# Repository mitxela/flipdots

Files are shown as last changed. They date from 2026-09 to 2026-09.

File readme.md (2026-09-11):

# Flipdot driver circuitry

KiCad designs and software for driving Hanover flipdot displays with a resolution of 13 by 28, as used in the [FLIP fluid on Flipdots project](https://mitxela.com/projects/flipflip)

- `drivers-full` are the main driver panels doing 13x8
- `drivers-half` are truncated to 13x4 for the end
- `decode` are boards with a ch32v003 to drive the shift registers
- `decode-sw` is firmware for the ch32, plus python scripts to show test patterns and video via a USB-RS485 adapter

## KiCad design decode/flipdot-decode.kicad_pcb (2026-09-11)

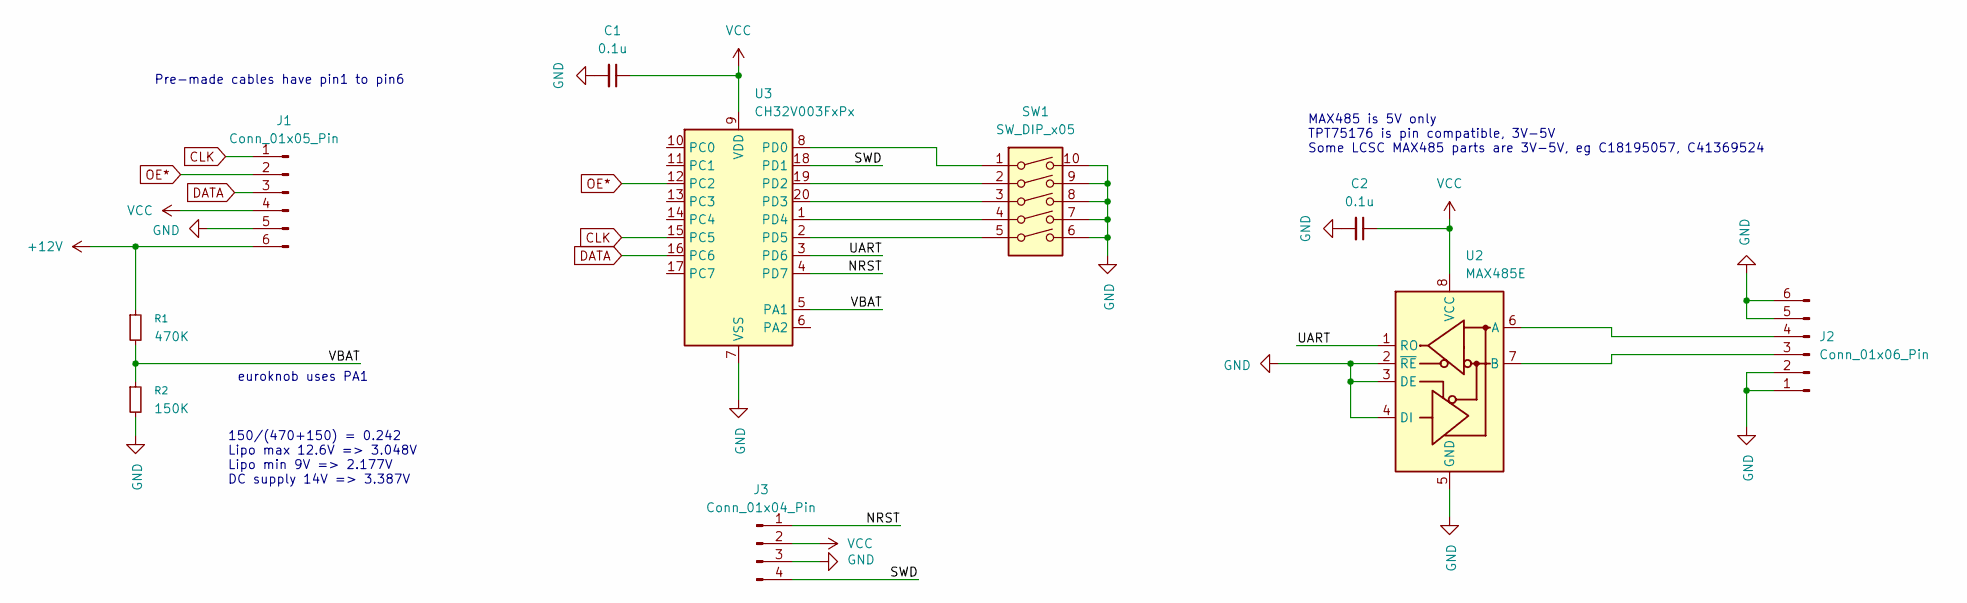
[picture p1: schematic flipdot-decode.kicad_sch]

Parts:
C1, C2: 0.1u; C_0603_1608Metric
J1: Conn_01x05_Pin; JST_ZH_B6B-ZR_1x06_P1.50mm_Vertical
J2: Conn_01x06_Pin; IDC-Header_2x03_P2.54mm_Vertical
J3: Conn_01x04_Pin; PinHeader_1x04_P2.54mm_Vertical
R1: 470K; R_0603_1608Metric
R2: 150K; R_0603_1608Metric
SW1: SW_DIP_x05; SW_DIP_SPSTx05_Slide_9.78x14.88mm_W7.62mm_P2.54mm
U2: MAX485E; SOIC-8_3.9x4.9mm_P1.27mm
U3: CH32V003FxPx; TSSOP-20_4.4x6.5mm_P0.65mm

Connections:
+12V: J1.6, R1.1
/NRST: J3.1, U3.4 (PD7)
/SWD: J3.4, U3.18 (PD1)
/UART: U2.1 (RO), U3.3 (PD6)
/VBAT: R1.2, R2.1, U3.5 (PA1)
CLK: J1.1, U3.15 (PC5)
DATA: J1.3, U3.16 (PC6)
GND: C1.2, C2.2, J1.5, J2.1, J2.2, J2.5, J2.6, J3.3, R2.2, SW1.6, SW1.7, SW1.8, SW1.9, SW1.10, U2.2 (~RE), U2.3 (DE), U2.4 (DI), U2.5 (GND), U3.7 (VSS)
unnamed: J2.3, U2.7 (B)
unnamed: J2.4, U2.6 (A)
unnamed: SW1.1, U3.8 (PD0)
unnamed: SW1.2, U3.19 (PD2)
unnamed: SW1.3, U3.20 (PD3)
unnamed: SW1.4, U3.1 (PD4)
unnamed: SW1.5, U3.2 (PD5)
OE*: J1.2, U3.12 (PC2)
VCC: C1.1, C2.1, J1.4, J3.2, U2.8 (VCC), U3.9 (VDD)

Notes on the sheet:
150/(470+150) = 0.242 Lipo max 12.6V => 3.048V Lipo min 9V => 2.177V DC supply 14V => 3.387V
euroknob uses PA1
MAX485 is 5V only TPT75176 is pin compatible, 3V-5V Some LCSC MAX485 parts are 3V-5V, eg C18195057, C41369524
Pre-made cables have pin1 to pin6

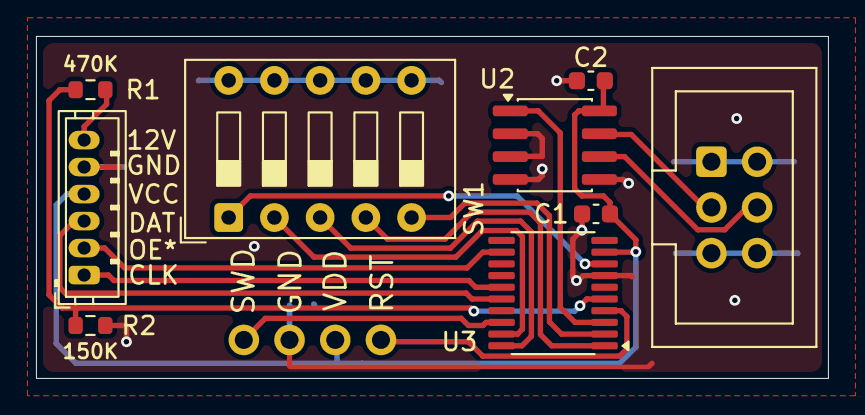
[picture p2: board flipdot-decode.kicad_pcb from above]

Board: 2 copper layers, 44.0 x 19.0 mm, 10 parts (0 on the bottom side), 17 nets.

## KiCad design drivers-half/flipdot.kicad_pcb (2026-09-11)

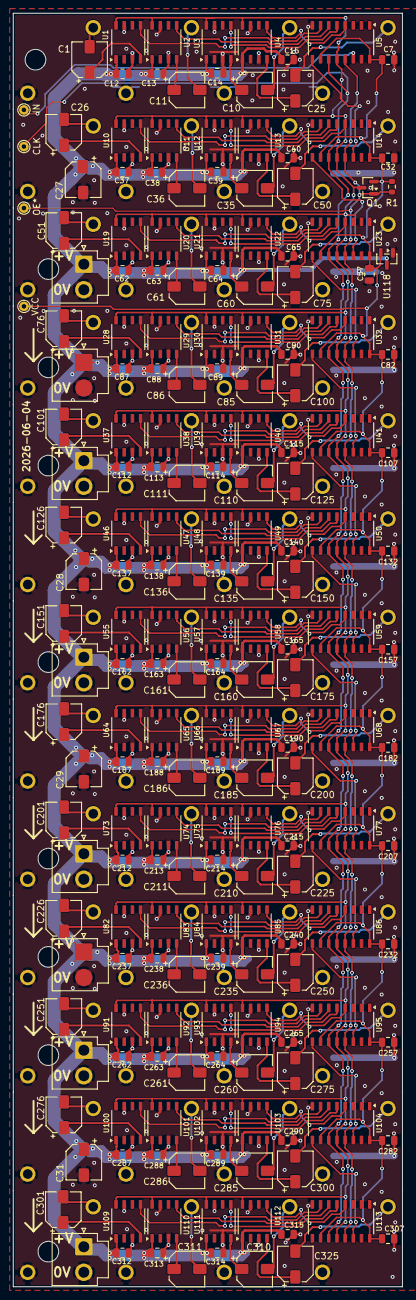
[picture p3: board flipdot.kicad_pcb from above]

Board: 2 copper layers, 60.4 x 197.5 mm, 262 parts (0 on the bottom side), 175 nets.

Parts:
C1, C10, C11, C25, C26, C27, C28, C29, C31, C35, C36, C50, C51, C60, C61, C75, C76, C85, C86, C100, C101, C110, C111, C125, C126, C135, C136, C150, C151, C160, C161, C175, C176, C185, C186, C200, C201, C210, C211, C225, C226, C235, C236, C250, C251, C260, C261, C275, C276, C285, C286, C300, C301, C310, C311, C325: 47u; CP_Elec_5x5.4_slim
C7, C12, C13, C14, C15, C32, C37, C38, C39, C40, C57, C62, C63, C64, C65, C82, C87, C88, C89, C90, C107, C112, C113, C114, C115, C132, C137, C138, C139, C140, C157, C162, C163, C164, C165, C182, C187, C188, C189, C190, C207, C212, C213, C214, C215, C232, C237, C238, C239, C240, C257, C262, C263, C264, C265, C282, C287, C288, C289, C290, C307, C312, C313, C314, C315: 10u; C_0805_2012Metric
H1, H5, H7, H9, H13, H17, H19, H21, H25: MountingHole; MountingHole_3.2mm_M3_DIN965
J10, J14, J18, J25, J34, J38, J41, J50: Conn_01x02_Pin; JST_VH_B2P-VH_1x02_P3.96mm_Vertical
L1, L2, L3, L4, L9, L10, L11, L12, L17, L18, L19, L20, L25, L26, L27, L28, L33, L34, L35, L36, L41, L42, L43, L44, L49, L50, L51, L52, L57, L58, L59, L60, L65, L66, L67, L68, L73, L74, L75, L76, L81, L82, L83, L84, L89, L90, L91, L92, L97, L98, L99, L100: Flipdot_single
Q1: FDN338P; SOT-23
R1: 100K; R_0603_1608Metric
TP1: IN; TestPoint_Pad_D1.5mm
TP4: CLK; TestPoint_Pad_D1.5mm
TP5: OE*; TestPoint_Pad_D1.5mm
TP7: VCC; TestPoint_Pad_D1.5mm
U1, U2, U3, U4, U10, U11, U12, U13, U19, U20, U21, U22, U28, U29, U30, U31, U37, U38, U39, U40, U46, U47, U48, U49, U55, U56, U57, U58, U64, U65, U66, U67, U73, U74, U75, U76, U82, U83, U84, U85, U91, U92, U93, U94, U100, U101, U102, U103, U109, U110, U111, U112: SOP-8_3.9x4.9mm_P1.27mm
U5, U14, U23, U32, U41, U50, U59, U68, U77, U86, U95, U104, U113: 74HC595; SOP-16_3.9x9.9mm_P1.27mm
U118: Megain MG6208T3-33; SOT-23

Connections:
+12V: C12.2, C13.2, C14.2, C15.2, C27.1, C28.1, C29.1, C31.1, C37.2, C38.2, C39.2, C40.2, C62.2, C63.2, C64.2, C65.2, C87.2, C88.2, C89.2, C90.2, C112.2, C113.2, C114.2, C115.2, C137.2, C138.2, C139.2, C140.2, C162.2, C163.2, C164.2, C165.2, C187.2, C188.2, C189.2, C190.2, C212.2, C213.2, C214.2, C215.2, C237.2, C238.2, C239.2, C240.2, C262.2, C263.2, C264.2, C265.2, C287.2, C288.2, C289.2, C290.2, C312.2, C313.2, C314.2, C315.2, J10.1, J14.1, J18.1, J25.1, J34.1, J38.1, J41.1, J50.1, U1.1 (VCC), U2.1 (VCC), U3.1 (VCC), U4.1 (VCC), U10.1 (VCC), U11.1 (VCC), U12.1 (VCC), U13.1 (VCC), U19.1 (VCC), U20.1 (VCC), U21.1 (VCC), U22.1 (VCC), U28.1 (VCC), U29.1 (VCC), U30.1 (VCC), U31.1 (VCC), U37.1 (VCC), U38.1 (VCC), U39.1 (VCC), U40.1 (VCC), U46.1 (VCC), U47.1 (VCC), U48.1 (VCC), U49.1 (VCC), U55.1 (VCC), U56.1 (VCC), U57.1 (VCC), U58.1 (VCC), U64.1 (VCC), U65.1 (VCC), U66.1 (VCC), U67.1 (VCC), U73.1 (VCC), U74.1 (VCC), U75.1 (VCC), U76.1 (VCC), U82.1 (VCC), U83.1 (VCC), U84.1 (VCC), U85.1 (VCC), U91.1 (VCC), U92.1 (VCC), U93.1 (VCC), U94.1 (VCC), U100.1 (VCC), U101.1 (VCC), U102.1 (VCC), U103.1 (VCC), U109.1 (VCC), U110.1 (VCC), U111.1 (VCC), U112.1 (VCC), U118.3 (VI)
/row1/DATA_IN: TP1.1 (1_1), U5.14 (SER)
/row1/DATA_OUT: U5.9 (QH'), U14.14 (SER)
/row2/DATA_OUT: U14.9 (QH'), U23.14 (SER)
/row3/DATA_OUT: U23.9 (QH'), U32.14 (SER)
/row4/DATA_OUT: U32.9 (QH'), U41.14 (SER)
/row5/DATA_OUT: U41.9 (QH'), U50.14 (SER)
/row6/DATA_OUT: U50.9 (QH'), U59.14 (SER)
/row7/DATA_OUT: U59.9 (QH'), U68.14 (SER)
/row8/DATA_OUT: U68.9 (QH'), U77.14 (SER)
/row10/DATA_IN: U77.9 (QH'), U86.14 (SER)
/row10/DATA_OUT: U86.9 (QH'), U95.14 (SER)
/row11/DATA_OUT: U95.9 (QH'), U104.14 (SER)
/row12/DATA_OUT: U104.9 (QH'), U113.14 (SER)
CLK: TP4.1 (1_1), U5.11 (SRCLK), U14.11 (SRCLK), U23.11 (SRCLK), U32.11 (SRCLK), U41.11 (SRCLK), U50.11 (SRCLK), U59.11 (SRCLK), U68.11 (SRCLK), U77.11 (SRCLK), U86.11 (SRCLK), U95.11 (SRCLK), U104.11 (SRCLK), U113.11 (SRCLK)
GND: C7.1, C12.1, C13.1, C14.1, C15.1, C27.2, C28.2, C29.2, C31.2, C32.1, C37.1, C38.1, C39.1, C40.1, C57.1, C62.1, C63.1, C64.1, C65.1, C82.1, C87.1, C88.1, C89.1, C90.1, C107.1, C112.1, C113.1, C114.1, C115.1, C132.1, C137.1, C138.1, C139.1, C140.1, C157.1, C162.1, C163.1, C164.1, C165.1, C182.1, C187.1, C188.1, C189.1, C190.1, C207.1, C212.1, C213.1, C214.1, C215.1, C232.1, C237.1, C238.1, C239.1, C240.1, C257.1, C262.1, C263.1, C264.1, C265.1, C282.1, C287.1, C288.1, C289.1, C290.1, C307.1, C312.1, C313.1, C314.1, C315.1, J10.2, J14.2, J18.2, J25.2, J34.2, J38.2, J41.2, J50.2, L1.1 (COL), L2.1 (COL), L3.1 (COL), L4.1 (COL), L9.1 (COL), L10.1 (COL), L11.1 (COL), L12.1 (COL), L17.1 (COL), L18.1 (COL), L19.1 (COL), L20.1 (COL), L25.1 (COL), L26.1 (COL), L27.1 (COL), L28.1 (COL), L33.1 (COL), L34.1 (COL), L35.1 (COL), L36.1 (COL), L41.1 (COL), L42.1 (COL), L43.1 (COL), L44.1 (COL), L49.1 (COL), L50.1 (COL), L51.1 (COL), L52.1 (COL), L57.1 (COL), L58.1 (COL), L59.1 (COL), L60.1 (COL), L65.1 (COL), L66.1 (COL), L67.1 (COL), L68.1 (COL), L73.1 (COL), L74.1 (COL), L75.1 (COL), L76.1 (COL), L81.1 (COL), L82.1 (COL), L83.1 (COL), L84.1 (COL), L89.1 (COL), L90.1 (COL), L91.1 (COL), L92.1 (COL), L97.1 (COL), L98.1 (COL), L99.1 (COL), L100.1 (COL), U1.3 (GND), U1.7 (GND), U2.3 (GND), U2.7 (GND), U3.3 (GND), U3.7 (GND), U4.3 (GND), U4.7 (GND), U5.8 (GND), U10.3 (GND), U10.7 (GND), U11.3 (GND), U11.7 (GND), U12.3 (GND), U12.7 (GND), U13.3 (GND), U13.7 (GND), U14.8 (GND), U19.3 (GND), U19.7 (GND), U20.3 (GND), U20.7 (GND), U21.3 (GND), U21.7 (GND), U22.3 (GND), U22.7 (GND), U23.8 (GND), U28.3 (GND), U28.7 (GND), U29.3 (GND), U29.7 (GND), U30.3 (GND), U30.7 (GND), U31.3 (GND), U31.7 (GND), U32.8 (GND), U37.3 (GND), U37.7 (GND), U38.3 (GND), U38.7 (GND), U39.3 (GND), U39.7 (GND), U40.3 (GND), U40.7 (GND), U41.8 (GND), U46.3 (GND), U46.7 (GND), U47.3 (GND), U47.7 (GND), U48.3 (GND), U48.7 (GND), U49.3 (GND), U49.7 (GND), U50.8 (GND), U55.3 (GND), U55.7 (GND), U56.3 (GND), U56.7 (GND), U57.3 (GND), U57.7 (GND), U58.3 (GND), U58.7 (GND), U59.8 (GND), U64.3 (GND), U64.7 (GND), U65.3 (GND), U65.7 (GND), U66.3 (GND), U66.7 (GND), U67.3 (GND), U67.7 (GND), U68.8 (GND), U73.3 (GND), U73.7 (GND), U74.3 (GND), U74.7 (GND), U75.3 (GND), U75.7 (GND), U76.3 (GND), U76.7 (GND), U77.8 (GND), U82.3 (GND), U82.7 (GND), U83.3 (GND), U83.7 (GND), U84.3 (GND), U84.7 (GND), U85.3 (GND), U85.7 (GND), U86.8 (GND), U91.3 (GND), U91.7 (GND), U92.3 (GND), U92.7 (GND), U93.3 (GND), U93.7 (GND), U94.3 (GND), U94.7 (GND), U95.8 (GND), U100.3 (GND), U100.7 (GND), U101.3 (GND), U101.7 (GND), U102.3 (GND), U102.7 (GND), U103.3 (GND), U103.7 (GND), U104.8 (GND), U109.3 (GND), U109.7 (GND), U110.3 (GND), U110.7 (GND), U111.3 (GND), U111.7 (GND), U112.3 (GND), U112.7 (GND), U113.8 (GND), U118.1 (GND)
LATCH: Q1.3 (D), U1.8 (AIN), U2.8 (AIN), U3.8 (AIN), U4.8 (AIN), U5.12 (RCLK), U10.8 (AIN), U11.8 (AIN), U12.8 (AIN), U13.8 (AIN), U14.12 (RCLK), U19.8 (AIN), U20.8 (AIN), U21.8 (AIN), U22.8 (AIN), U23.12 (RCLK), U28.8 (AIN), U29.8 (AIN), U30.8 (AIN), U31.8 (AIN), U32.12 (RCLK), U37.8 (AIN), U38.8 (AIN), U39.8 (AIN), U40.8 (AIN), U41.12 (RCLK), U46.8 (AIN), U47.8 (AIN), U48.8 (AIN), U49.8 (AIN), U50.12 (RCLK), U55.8 (AIN), U56.8 (AIN), U57.8 (AIN), U58.8 (AIN), U59.12 (RCLK), U64.8 (AIN), U65.8 (AIN), U66.8 (AIN), U67.8 (AIN), U68.12 (RCLK), U73.8 (AIN), U74.8 (AIN), U75.8 (AIN), U76.8 (AIN), U77.12 (RCLK), U82.8 (AIN), U83.8 (AIN), U84.8 (AIN), U85.8 (AIN), U86.12 (RCLK), U91.8 (AIN), U92.8 (AIN), U93.8 (AIN), U94.8 (AIN), U95.12 (RCLK), U100.8 (AIN), U101.8 (AIN), U102.8 (AIN), U103.8 (AIN), U104.12 (RCLK), U109.8 (AIN), U110.8 (AIN), U111.8 (AIN), U112.8 (AIN), U113.12 (RCLK)
unnamed: C1.2, L1.2 (ROW)
unnamed: C11.2, L2.2 (ROW)
unnamed: C10.2, L3.2 (ROW)
unnamed: C25.2, L4.2 (ROW)
unnamed: C26.2, L9.2 (ROW)
unnamed: C36.2, L10.2 (ROW)
unnamed: C35.2, L11.2 (ROW)
unnamed: C50.2, L12.2 (ROW)
unnamed: C51.2, L17.2 (ROW)
unnamed: C61.2, L18.2 (ROW)
unnamed: C60.2, L19.2 (ROW)
unnamed: C75.2, L20.2 (ROW)
unnamed: C76.2, L25.2 (ROW)
unnamed: C86.2, L26.2 (ROW)
unnamed: C85.2, L27.2 (ROW)
unnamed: C100.2, L28.2 (ROW)
unnamed: C101.2, L33.2 (ROW)
unnamed: C111.2, L34.2 (ROW)
unnamed: C110.2, L35.2 (ROW)
unnamed: C125.2, L36.2 (ROW)
unnamed: C126.2, L41.2 (ROW)
unnamed: C136.2, L42.2 (ROW)
unnamed: C135.2, L43.2 (ROW)
unnamed: C150.2, L44.2 (ROW)
unnamed: C151.2, L49.2 (ROW)
unnamed: C161.2, L50.2 (ROW)
unnamed: C160.2, L51.2 (ROW)
unnamed: C175.2, L52.2 (ROW)
unnamed: C176.2, L57.2 (ROW)
unnamed: C186.2, L58.2 (ROW)
unnamed: C185.2, L59.2 (ROW)
unnamed: C200.2, L60.2 (ROW)
unnamed: C201.2, L65.2 (ROW)
unnamed: C211.2, L66.2 (ROW)
unnamed: C210.2, L67.2 (ROW)
unnamed: C225.2, L68.2 (ROW)
unnamed: C226.2, L73.2 (ROW)
unnamed: C236.2, L74.2 (ROW)
unnamed: C235.2, L75.2 (ROW)
unnamed: C250.2, L76.2 (ROW)
unnamed: C251.2, L81.2 (ROW)
unnamed: C261.2, L82.2 (ROW)
unnamed: C260.2, L83.2 (ROW)
unnamed: C275.2, L84.2 (ROW)
unnamed: C276.2, L89.2 (ROW)
unnamed: C286.2, L90.2 (ROW)
unnamed: C285.2, L91.2 (ROW)
unnamed: C300.2, L92.2 (ROW)
unnamed: C301.2, L97.2 (ROW)
unnamed: C311.2, L98.2 (ROW)
unnamed: C310.2, L99.2 (ROW)
unnamed: C325.2, L100.2 (ROW)
unnamed: C1.1, U1.4 (AOUT)
unnamed: U1.5 (BIN), U5.7 (QH)
unnamed: C11.1, U2.4 (AOUT)
unnamed: U2.5 (BIN), U5.6 (QG)
unnamed: C10.1, U3.4 (AOUT)
unnamed: U3.5 (BIN), U5.5 (QF)
unnamed: C25.1, U4.4 (AOUT)
unnamed: U4.5 (BIN), U5.4 (QE)
unnamed: C26.1, U10.4 (AOUT)
unnamed: U10.5 (BIN), U14.7 (QH)
unnamed: C36.1, U11.4 (AOUT)
unnamed: U11.5 (BIN), U14.6 (QG)
unnamed: C35.1, U12.4 (AOUT)
unnamed: U12.5 (BIN), U14.5 (QF)
unnamed: C50.1, U13.4 (AOUT)
unnamed: U13.5 (BIN), U14.4 (QE)
unnamed: C51.1, U19.4 (AOUT)
unnamed: U19.5 (BIN), U23.7 (QH)
unnamed: C61.1, U20.4 (AOUT)
unnamed: U20.5 (BIN), U23.6 (QG)
unnamed: C60.1, U21.4 (AOUT)
unnamed: U21.5 (BIN), U23.5 (QF)
unnamed: C75.1, U22.4 (AOUT)
unnamed: U22.5 (BIN), U23.4 (QE)
unnamed: C76.1, U28.4 (AOUT)
unnamed: U28.5 (BIN), U32.7 (QH)
unnamed: C86.1, U29.4 (AOUT)
unnamed: U29.5 (BIN), U32.6 (QG)
unnamed: C85.1, U30.4 (AOUT)
unnamed: U30.5 (BIN), U32.5 (QF)
unnamed: C100.1, U31.4 (AOUT)
unnamed: U31.5 (BIN), U32.4 (QE)
unnamed: C101.1, U37.4 (AOUT)
unnamed: U37.5 (BIN), U41.7 (QH)
unnamed: C111.1, U38.4 (AOUT)
unnamed: U38.5 (BIN), U41.6 (QG)
unnamed: C110.1, U39.4 (AOUT)
unnamed: U39.5 (BIN), U41.5 (QF)
unnamed: C125.1, U40.4 (AOUT)
unnamed: U40.5 (BIN), U41.4 (QE)
unnamed: C126.1, U46.4 (AOUT)
unnamed: U46.5 (BIN), U50.7 (QH)
unnamed: C136.1, U47.4 (AOUT)
unnamed: U47.5 (BIN), U50.6 (QG)
unnamed: C135.1, U48.4 (AOUT)
unnamed: U48.5 (BIN), U50.5 (QF)
unnamed: C150.1, U49.4 (AOUT)
unnamed: U49.5 (BIN), U50.4 (QE)
unnamed: C151.1, U55.4 (AOUT)
unnamed: U55.5 (BIN), U59.7 (QH)
unnamed: C161.1, U56.4 (AOUT)
unnamed: U56.5 (BIN), U59.6 (QG)
unnamed: C160.1, U57.4 (AOUT)
unnamed: U57.5 (BIN), U59.5 (QF)
unnamed: C175.1, U58.4 (AOUT)
unnamed: U58.5 (BIN), U59.4 (QE)
unnamed: C176.1, U64.4 (AOUT)
unnamed: U64.5 (BIN), U68.7 (QH)
unnamed: C186.1, U65.4 (AOUT)
unnamed: U65.5 (BIN), U68.6 (QG)
unnamed: C185.1, U66.4 (AOUT)
unnamed: U66.5 (BIN), U68.5 (QF)
unnamed: C200.1, U67.4 (AOUT)
unnamed: U67.5 (BIN), U68.4 (QE)
unnamed: C201.1, U73.4 (AOUT)
unnamed: U73.5 (BIN), U77.7 (QH)
unnamed: C211.1, U74.4 (AOUT)
unnamed: U74.5 (BIN), U77.6 (QG)
unnamed: C210.1, U75.4 (AOUT)
unnamed: U75.5 (BIN), U77.5 (QF)
unnamed: C225.1, U76.4 (AOUT)
unnamed: U76.5 (BIN), U77.4 (QE)
unnamed: C226.1, U82.4 (AOUT)
unnamed: U82.5 (BIN), U86.7 (QH)
unnamed: C236.1, U83.4 (AOUT)
unnamed: U83.5 (BIN), U86.6 (QG)
unnamed: C235.1, U84.4 (AOUT)
unnamed: U84.5 (BIN), U86.5 (QF)
unnamed: C250.1, U85.4 (AOUT)
unnamed: U85.5 (BIN), U86.4 (QE)
unnamed: C251.1, U91.4 (AOUT)
unnamed: U91.5 (BIN), U95.7 (QH)
unnamed: C261.1, U92.4 (AOUT)
unnamed: U92.5 (BIN), U95.6 (QG)
unnamed: C260.1, U93.4 (AOUT)
unnamed: U93.5 (BIN), U95.5 (QF)
unnamed: C275.1, U94.4 (AOUT)
unnamed: U94.5 (BIN), U95.4 (QE)
unnamed: C276.1, U100.4 (AOUT)
unnamed: U100.5 (BIN), U104.7 (QH)
unnamed: C286.1, U101.4 (AOUT)
unnamed: U101.5 (BIN), U104.6 (QG)
unnamed: C285.1, U102.4 (AOUT)
unnamed: U102.5 (BIN), U104.5 (QF)
unnamed: C300.1, U103.4 (AOUT)
unnamed: U103.5 (BIN), U104.4 (QE)
unnamed: C301.1, U109.4 (AOUT)
unnamed: U109.5 (BIN), U113.7 (QH)
unnamed: C311.1, U110.4 (AOUT)
unnamed: U110.5 (BIN), U113.6 (QG)
unnamed: C310.1, U111.4 (AOUT)
unnamed: U111.5 (BIN), U113.5 (QF)
unnamed: C325.1, U112.4 (AOUT)
unnamed: U112.5 (BIN), U113.4 (QE)
OE*: Q1.1 (G), R1.2, TP5.1 (1_1), U5.13 (~OE), U14.13 (~OE), U23.13 (~OE), U32.13 (~OE), U41.13 (~OE), U50.13 (~OE), U59.13 (~OE), U68.13 (~OE), U77.13 (~OE), U86.13 (~OE), U95.13 (~OE), U104.13 (~OE), U113.13 (~OE)
VCC: C7.2, C32.2, C57.2, C82.2, C107.2, C132.2, C157.2, C182.2, C207.2, C232.2, C257.2, C282.2, C307.2, Q1.2 (S), R1.1, TP7.1 (1_1), U5.10 (~SRCLR), U5.16 (VCC), U14.10 (~SRCLR), U14.16 (VCC), U23.10 (~SRCLR), U23.16 (VCC), U32.10 (~SRCLR), U32.16 (VCC), U41.10 (~SRCLR), U41.16 (VCC), U50.10 (~SRCLR), U50.16 (VCC), U59.10 (~SRCLR), U59.16 (VCC), U68.10 (~SRCLR), U68.16 (VCC), U77.10 (~SRCLR), U77.16 (VCC), U86.10 (~SRCLR), U86.16 (VCC), U95.10 (~SRCLR), U95.16 (VCC), U104.10 (~SRCLR), U104.16 (VCC), U113.10 (~SRCLR), U113.16 (VCC), U118.2 (VO)

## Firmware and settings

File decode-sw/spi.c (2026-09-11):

#include "ch32fun.h"
#include <stdio.h>

// MOSI   PC6
// SCK    PC5
// OE/LATCH* PC2

// UART RX PD6
// LED  PC1

#define LED (1<<1)
#define OE (1<<2)

#define PAGESIZE (13*4)

#define pulseLength 2000
#define tempdelay 500



// 150/(470+150) = 0.242
// 3S lipo, cut out at 9.0V
// 9.0*150/(470+150) *1023/3.3 = 675 

#define VBAT_LOW       650 // ~9.0
#define VBAT_RELEASE   700 // ~9.6

static inline uint16_t read_adc(){
	ADC1->CTLR2 |= ADC_SWSTART;
	while(!(ADC1->STATR & ADC_EOC));
	return ADC1->RDATAR;//[0...1023]
}

uint8_t uart_rx(){
	while (!(USART1->STATR & USART_STATR_RXNE));
	return USART1->DATAR;
}

void send_spi(uint8_t data) {
	GPIOC->OUTDR |= OE;

	// wait for TXE
	while(!(SPI1->STATR & SPI_STATR_TXE));
	// Send byte
	SPI1->DATAR = data;

	while(SPI1->STATR & SPI_STATR_BSY);

	GPIOC->OUTDR &= ~OE;
	Delay_Us(pulseLength);
	GPIOC->OUTDR |= OE;
}

void send_page(uint8_t * data){
	GPIOC->OUTDR &= ~LED;

	for (int i=0;i<13*4;i++) {
		// wait for TXE
		while(!(SPI1->STATR & SPI_STATR_TXE));
		// Send byte
		SPI1->DATAR = data[i];
		while(SPI1->STATR & SPI_STATR_BSY);
	}

	// best time to check battery is right before a pulse
	if (read_adc() < VBAT_LOW ) {
		do {
			Delay_Ms(500);
			GPIOC->OUTDR |= LED;
			Delay_Ms(500);
			GPIOC->OUTDR &= ~LED;
			//printf("adc %d\n",read_adc());
		} while (read_adc()<VBAT_RELEASE);
	} else {
		GPIOC->OUTDR &= ~OE;
		Delay_Us(pulseLength);
		GPIOC->OUTDR |= OE;
	}
	GPIOC->OUTDR |= LED;
}

void repulse_delay(int d, int s){
	for (int i=0;i<d;i+=s) {
		Delay_Ms(s);
		GPIOC->OUTDR &= ~OE;
		Delay_Us(pulseLength);
		GPIOC->OUTDR |= OE;
	}
}

void init_adc()
{
	RCC->APB2PCENR |= RCC_APB2Periph_GPIOA | RCC_APB2Periph_ADC1;

	// PA1 is analog input chl 1
	GPIOA->CFGLR &= ~(0xf<<(4*1));	// CNF = 00: Analog, MODE = 00: Input

	RCC->APB2PRSTR |= RCC_APB2Periph_ADC1;
	RCC->APB2PRSTR &= ~RCC_APB2Periph_ADC1;

	RCC->CFGR0 &= ~(0x1F<<11); //RCC_ADCPRE = 0
	ADC1->RSQR1 = 0;
	ADC1->RSQR2 = 0;
	ADC1->RSQR3 = 1;
	// sampling time
	ADC1->SAMPTR2 &= ~(ADC_SMP0<<(3*7));
	ADC1->SAMPTR2 |= 7<<(3*7);

	// turn on, set sw trig
	ADC1->CTLR2 |= ADC_ADON | ADC_EXTSEL;
	// reset calibration
	ADC1->CTLR2 |= ADC_RSTCAL;
	while(ADC1->CTLR2 & ADC_RSTCAL);
	// calibrate
	ADC1->CTLR2 |= ADC_CAL;
	while(ADC1->CTLR2 & ADC_CAL);
}

uint8_t page[PAGESIZE] = {};

int main()
{
	SystemInit();


	RCC->APB2PCENR |= RCC_APB2Periph_GPIOC | RCC_APB2Periph_SPI1 | RCC_APB2Periph_GPIOD | RCC_APB2Periph_USART1;

	GPIOC->CFGLR &= ~((0xf<<(4*6)) | (0xf<<(4*5)) | (0xf<<(4*2)) | (0xf<<(4*1)) );
	GPIOC->CFGLR |=((GPIO_Speed_10MHz | GPIO_CNF_OUT_PP_AF)<<(4*5))
				 | ((GPIO_Speed_10MHz | GPIO_CNF_OUT_PP_AF)<<(4*6))
				 | ((GPIO_Speed_10MHz | GPIO_CNF_OUT_PP)<<(4*1))
				 | ((GPIO_Speed_10MHz | GPIO_CNF_OUT_PP)<<(4*2));

	GPIOC->OUTDR |= OE;

	// ID pins on D0,D2,D3,D4,D5
	GPIOD->CFGLR &= ~((0xf<<(4*0)) | (0xf<<(4*2)) | (0xf<<(4*3)) | (0xf<<(4*4)) | (0xf<<(4*5)) );
	GPIOD->CFGLR |=((GPIO_Speed_In | GPIO_CNF_IN_PUPD)<<(4*0))
				 | ((GPIO_Speed_In | GPIO_CNF_IN_PUPD)<<(4*2))
				 | ((GPIO_Speed_In | GPIO_CNF_IN_PUPD)<<(4*3))
				 | ((GPIO_Speed_In | GPIO_CNF_IN_PUPD)<<(4*4))
				 | ((GPIO_Speed_In | GPIO_CNF_IN_PUPD)<<(4*5));
	GPIOD->BSHR = GPIO_BSHR_BS0 |
				  GPIO_BSHR_BS2 |
				  GPIO_BSHR_BS3 |
				  GPIO_BSHR_BS4 |
				  GPIO_BSHR_BS5;

	// Configure SPI 
	SPI1->CTLR1 = 
		SPI_NSS_Soft | SPI_CPHA_1Edge | SPI_CPOL_Low | SPI_DataSize_8b |
		SPI_Mode_Master | SPI_Direction_1Line_Tx |
		SPI_BaudRatePrescaler_8;

	// enable SPI port
	SPI1->CTLR1 |= CTLR1_SPE_Set;

	// enable UART
	USART1->CTLR1 = USART_WordLength_8b | USART_Parity_No | USART_Mode_Rx;
	USART1->CTLR2 = USART_StopBits_1;
	USART1->CTLR3 = USART_HardwareFlowControl_None;
	USART1->BRR = 48; // 1000kbps
	USART1->CTLR1 |= CTLR1_UE_Set;

	init_adc();

	GPIOC->OUTDR |= LED;

	int frame = ((GPIOD->INDR) &1) | (((GPIOD->INDR) >>1)&0b11110);


	sync:
	if (uart_rx() !='M') goto sync;
	if (uart_rx() !='a') goto sync;
	if (uart_rx() !='g') goto sync;
	if (uart_rx() !='i') goto sync;
	uint8_t totalFrames = uart_rx();


	for (int i=0;i<frame * PAGESIZE;i++) {
		uart_rx();
	}

	for (int i=0;i<PAGESIZE;i++) {
		page[i]=uart_rx();
	}

	for (int i=0;i<(totalFrames-frame-1) * PAGESIZE;i++) {
		uart_rx();
	}

	if (uart_rx() !='\n') goto sync; // maybe between each frame too?

	send_page(page);

	goto sync;

}

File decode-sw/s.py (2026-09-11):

import serial, time
s=serial.Serial("/dev/ttyUSB0",1000000)

totalFrames = 2;

#for i in range(255):
while True:

	s.write(b"Magi")
	s.write([totalFrames])
	s.write([0x00,0x00,0x00,0x00]*13)
	s.write([0xAA,0xAA,0x55,0x55]*13)
	s.write([0x0A])

	time.sleep(0.5)

	s.write(b"Magi")
	s.write([totalFrames])
	s.write([0xAA,0xAA,0x55,0x55]*13)
	s.write([0x00,0x00,0x00,0x00]*13)
	s.write([0x0A])

	time.sleep(0.5)

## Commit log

2025-09-02 use JST ZH
    [flipdot.kicad_pcb, flipdot.kicad_sch]
2025-09-02 keepout in wrong place
    [flipdot.kicad_pcb]
2025-09-02 flip everything again
    [flipdot.kicad_pcb, flipdot.kicad_sch]
2025-09-02 some progress
    [flipdot.kicad_pcb, flipdot.kicad_sch]
2025-09-03 mounting holes
    [flipdot.kicad_pcb, flipdot.kicad_sch]
2025-09-04 fatten 12v line
    [flipdot.kicad_pcb, flipdot.kicad_sch]
2025-09-04 single row mostly complete
    [flipdot.kicad_pcb, flipdot.kicad_sch]
2025-09-04 use single component for connector
    [flipdot.kicad_pcb, flipdot.kicad_sch]
2025-09-04 geographic reannotate
    [flipdot.kicad_pcb, flipdot.kicad_sch]
2025-09-08 split into separate sheets
    [dotrow.kicad_sch, flipdot.kicad_pcb, flipdot.kicad_sch]
2025-09-08 reannotate to match pcb layout
    [dotrow.kicad_sch]
2025-09-08 valid 13 row layout
    [dotrow.kicad_sch, flipdot.kicad_pcb]
2025-09-09 add LEDs
    [flipdot.kicad_pcb, flipdot.kicad_sch]
2025-09-11 more thermal relief
    [flipdot.kicad_pcb]
2026-03-17 Start on switching to electrolytics
    [dotrow.kicad_sch, flipdot.kicad_pcb, flipdot.kicad_sch]
2026-03-27 add mosfet
    [dotrow.kicad_sch, flipdot.kicad_pcb, flipdot.kicad_sch]
2026-03-28 move to kicad 10
2026-03-28 replace data connectors with just two 5-pin ZH
    [dotrow.kicad_sch, flipdot.kicad_sch]
2026-03-28 The slow and painful process begins
    [dotrow.kicad_sch, flipdot.kicad_pcb, flipdot.kicad_sch]
2026-03-28 first three dots mostly wired up
    [flipdot.kicad_pcb]
2026-03-28 six dots routed
    [flipdot.kicad_pcb]
2026-03-28 53 unrouted
    [flipdot.kicad_pcb]
2026-03-28 0 unrouted
    [flipdot.kicad_pcb]
2026-03-29 drc fixes
    [flipdot.kicad_pcb]
2026-03-29 fix 3d models
    [flipdot.kicad_pcb]
2026-03-29 start on routing data to left/right
    [flipdot.kicad_pcb]
2026-03-29 schematic parity
    [flipdot.kicad_pcb]
2026-03-29 left/right test pads added
    [flipdot.kicad_pcb, flipdot.kicad_sch]
2026-03-29 silk screen mostly passable
    [flipdot.kicad_pcb]
2026-03-29 add more electrolytics for 12v
    [flipdot.kicad_pcb, flipdot.kicad_sch]
2026-03-30 add 12v out with polyfuse
    [flipdot.kicad_pcb, flipdot.kicad_sch]
2026-03-30 add regulator after all
    [flipdot.kicad_pcb, flipdot.kicad_sch]
2026-03-30 gerbers generated
    [flipdot.kicad_pcb]
2026-04-15 before second prototype
2026-04-15 repulse to recharge capacitors during long delay
2026-05-13 snort in uart
2026-05-18 use through-hole pads for cross links
    [flipdot.kicad_pcb]
2026-05-18 remove unused LEDs
    [flipdot.kicad_pcb, flipdot.kicad_sch]
2026-05-20 board designed
    [flipdot-decode.kicad_pcb, flipdot-decode.kicad_sch]
2026-05-20 add reset pin
    [flipdot-decode.kicad_pcb, flipdot-decode.kicad_sch]
2026-05-31 starting on battery check
2026-06-01 battery check ok
2026-06-04 mark rectangles for plywood
    [flipdot.kicad_pcb]
2026-06-04 initial halfboard
    [flipdot.kicad_pcb]
2026-06-04 add 12v caps back in
    [flipdot.kicad_pcb]
2026-09-11 cleanup to subdir
    [dotrow.kicad_sch, flipdot.kicad_pcb, flipdot.kicad_sch]
